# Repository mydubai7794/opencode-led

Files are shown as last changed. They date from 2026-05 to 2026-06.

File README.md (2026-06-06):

# AI LED Light

AI 编程助手实体指示灯 — 将 AI 编程助手的实时状态映射到桌面 LED 灯效，让你**一眼看到 AI 在干什么**。

支持 [OpenCode](https://opencode.ai) 插件和 [Claude Code](https://docs.anthropic.com/en/docs/claude-code) CLI，也兼容任何能发 MQTT 消息的 AI 编程工具。

## 功能特点

- **实时状态映射**：AI 思考时黄灯旋转、需要授权时红灯常亮、任务完成时绿灯、空闲时蓝灯呼吸、出错时红灯闪烁
- **一键安装**：`install.sh`（Linux/macOS）或 `install.bat`（Windows）安装依赖 + 部署插件，重启 OpenCode 即可使用
- **Claude Code 支持**：`install-claude.sh` / `install-claude.bat` 自动配置 Claude Code hooks，重启即可使用
- **跨平台 SSL**：Web 烧录服务器自动生成自签名证书，Windows/Linux/macOS 均可使用 HTTPS
- **双模式 MQTT**：支持本地内嵌 Broker（局域网）和远程 Mosquitto Broker（公网）
- **多项目协调**：多个 OpenCode / Claude Code 实例同时运行时，自动取最高优先级状态
- **Web 烧录器**：Chrome/Edge 浏览器直接烧录 ESP32 固件，零安装
- **WiFi 配网**：ESP32 开启热点，手机浏览器一键配网，无需写死配置
- **支持多款芯片**：ESP32-C3（WS2812 RGB 灯带）和 ESP8266（PWM LED）

## 架构

### 本地模式（默认）

```
┌─── 你的电脑（开发机）──────────────────────────────────────┐
│                                                            │
│  ┌─ OpenCode ─────────┐  ┌─ Claude Code ──────────────┐   │
│  │ ai-led.js 插件      │  │ hooks → claude-led-hook.mjs│   │
│  │  (进程内，捕获事件)   │  │  (每次事件 spawn)           │   │
│  │       │             │  │       │ HTTP POST            │   │
│  └───────┼─────────────┘  └───────┼────────────────────┘   │
│          │                        ↓                         │
│          │              claude-led-daemon.mjs               │
│          │              (常驻进程，持有 MQTT 连接)            │
│          ↓                        ↓                         │
│  MQTT publish ──────→ 内嵌 Broker (1883)                    │
│                                     │                      │
└─────────────────────────────────────┼──────────────────────┘
                                │ WiFi 局域网
                                ↓
                    ┌───────────────────────┐
                    │  ESP32 + WS2812 LED   │
                    │                       │
                    │  1. 连 WiFi           │
                    │  2. 连 MQTT Broker    │
                    │  3. 订阅 ai-led/state │
                    │  4. state → 灯效       │
                    └───────────────────────┘
```

### 远程模式

```
┌─── 你的电脑（开发机）──────────────────────────────────────┐
│                                                            │
│  ┌─ OpenCode ─────────┐  ┌─ Claude Code ──────────────┐   │
│  │ ai-led.js 插件      │  │ hooks → claude-led-hook.mjs│   │
│  │       │             │  │       │ HTTP POST            │   │
│  └───────┼─────────────┘  └───────┼────────────────────┘   │
│          │                        ↓                         │
│          │              claude-led-daemon.mjs               │
│          ↓                        ↓                         │
│  MQTT publish ──────→ 远程 Broker (公网)                    │
│                                     │                      │
└─────────────────────────────────────┼──────────────────────┘
                                │ 互联网
                                ↓
                    ┌───────────────────────┐
                    │  远程 Mosquitto Broker │
                    │  (Docker, 端口 1883)   │
                    │  需要用户名密码认证      │
                    └───────────┬───────────┘
                                │ 互联网/WiFi
                                ↓
                    ┌───────────────────────┐
                    │  ESP32 + WS2812 LED   │
                    │  连接远程 Broker       │
                    └───────────────────────┘
```

## LED 状态映射

| 状态 | LED 效果 | 触发条件 |
|---|---|---|
| `thinking` | 黄色跑马灯旋转 | AI 思考/输出/执行工具 |
| `auth_required` | 红灯常亮 | 需要用户授权 |
| `done` | 绿灯常亮 | 任务完成 |
| `idle` | 蓝灯呼吸(2s) | 空闲待机 |
| `error` | 红灯慢闪(1.6s) | 出错 |
| `config` | 紫灯呼吸(800ms) | 配网模式 |

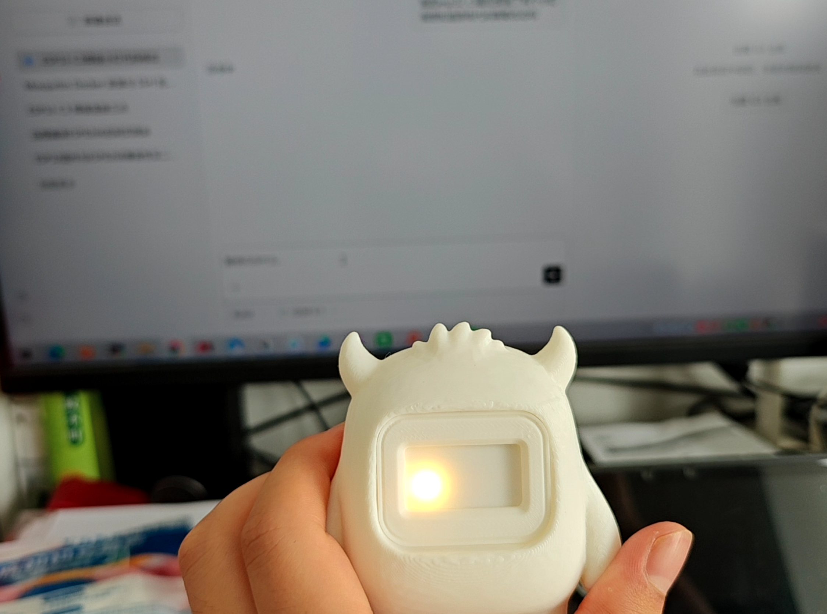
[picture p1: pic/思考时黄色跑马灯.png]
思考时黄色跑马灯

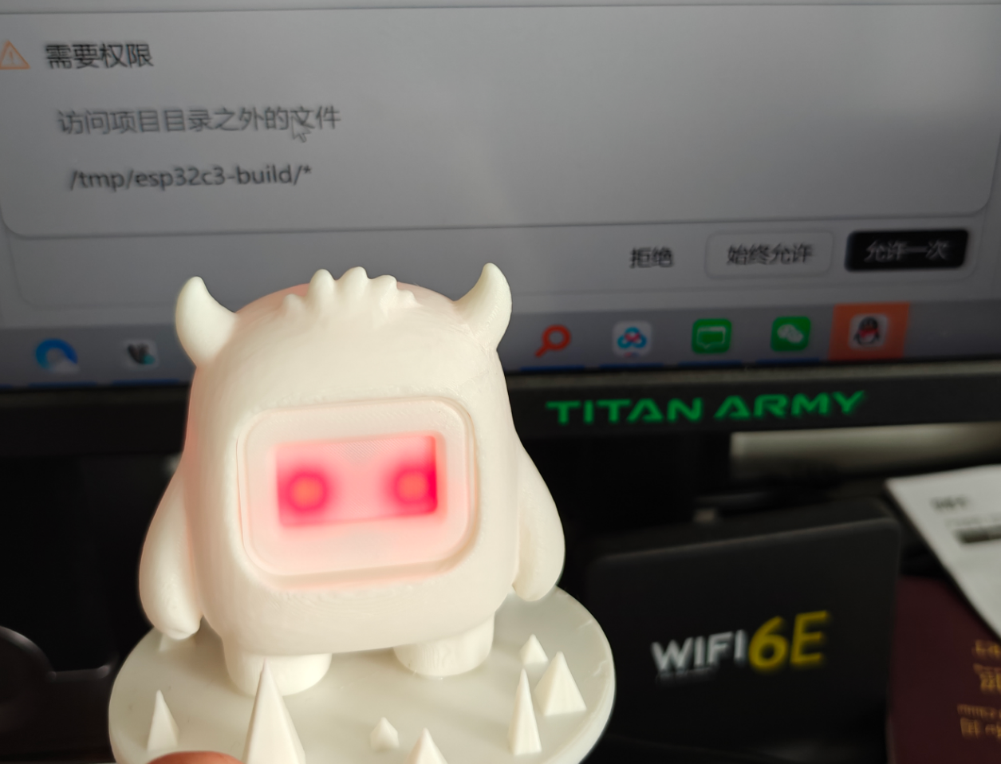
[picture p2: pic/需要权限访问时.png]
需要权限访问时

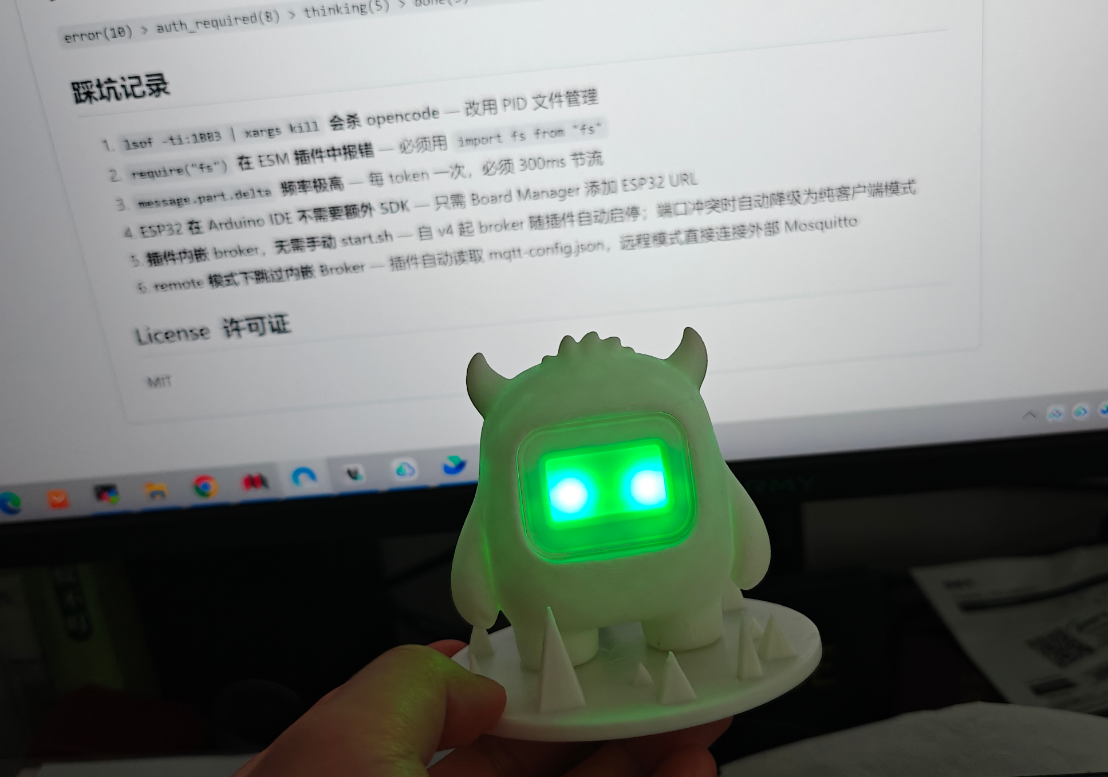
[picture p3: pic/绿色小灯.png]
绿色小灯

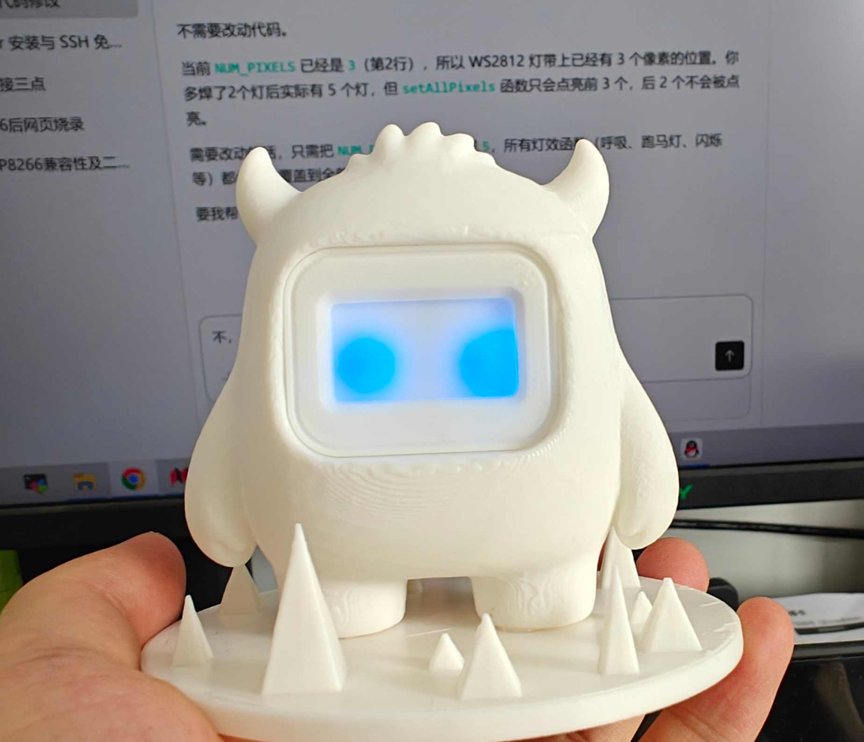
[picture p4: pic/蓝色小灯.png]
蓝色小灯


## 快速开始

### 0. 一句话提示词（给 AI 助手）

将以下提示词粘贴到你的 AI 编程助手（如 OpenCode）中，它会自动完成安装：

```
请克隆 https://github.com/mydubai7794/opencode-led 仓库，根据当前操作系统执行对应的安装脚本（Linux/macOS 用 bash install.sh，Windows 用 install.bat），安装完成后以本地模式启动插件。查看 README.md 了解详细用法。
```

### 1. 安装插件（OpenCode）

**Linux / macOS：**
```bash
git clone https://github.com/mydubai7794/opencode-led.git
cd opencode-led
bash install.sh
opencode
```

**Windows：**
```cmd
git clone https://github.com/mydubai7794/opencode-led.git
cd opencode-led
install.bat
opencode
```

无需手动启动 broker，插件加载时自动管理 MQTT Broker 生命周期。

### 1b. 安装插件（Claude Code）

**Linux / macOS：**
```bash
git clone https://github.com/mydubai7794/opencode-led.git
cd opencode-led
bash install-claude.sh
```

**Windows：**
```cmd
git clone https://github.com/mydubai7794/opencode-led.git
cd opencode-led
install-claude.bat
```

安装完成后重启 Claude Code 即可。LED daemon 会在首次使用时自动启动，无需手动操作。

**管理命令：**
```bash
npm run daemon:start   # 手动启动 daemon
npm run daemon:stop    # 停止 daemon
npm run daemon:status  # 查看运行状态
```

### 2. 配置 MQTT 模式

在项目根目录创建 `mqtt-config.json`（**已在 `.gitignore` 中，不会泄露凭据**），`install.sh` 安装时会自动复制到 `~/.config/opencode/plugins/` 目录。

> **local 模式**（局域网）只需要 `wifi` 和 `local` 即可，`remote` 部分可不填。

```json
{
  "mode": "local",
  "wifi": {
    "ssid": "你的WiFi名称",
    "password": "你的WiFi密码"
  },
  "local": {
    "host": "127.0.0.1",
    "port": 1883
  },
  "remote": {
    "host": "your-broker-ip",
    "port": 1883,
    "username": "",
    "password": ""
  }
}
```

| 字段 | 说明 |
|---|---|
| `mode` | `"local"` 或 `"remote"` |
| `wifi` | WiFi 凭据，编译固件时使用（插件忽略此字段） |
| `local.host/port` | 本地内嵌 Broker 地址（local 模式使用） |
| `remote.host/port` | 远程 Mosquitto Broker 地址（remote 模式使用） |
| `remote.username/password` | 远程 Broker 认证凭据（remote 模式必填） |

- **local 模式**：插件自动启动内嵌 aedes Broker，ESP32 与电脑在同一局域网
- **remote 模式**：连接远程 Mosquitto Broker，ESP32 可通过互联网访问，跳过内嵌 Broker

### 3. 开发调试

**Linux / macOS：**
```bash
npm install              # 安装依赖
bash start.sh            # 启动独立 Broker + Subscriber
node test-publisher.js   # 发送测试消息
bash stop.sh             # 停止（安全，不影响 opencode）
```

**Windows：**
```cmd
npm install
start.bat
node test-publisher.js
stop.bat
```

## 3D 打印外壳

项目提供了一个怪兽造型 LED 外壳的 3D 打印模型文件，适配 ESP32-C3 + WS2812 方案：

- **文件位置**：`model/monster-led-case.3mf`
- **格式**：.3mf（推荐使用 [Bambu Studio](https://bambulab.com/en/download/bambu-studio) 打开）
- **适配**：ESP32-C3 Super Mini + 2 颗 WS2812B 灯珠，USB-C 口对外露出
- **演示**：拓竹 A1 打印

## 硬件物料清单

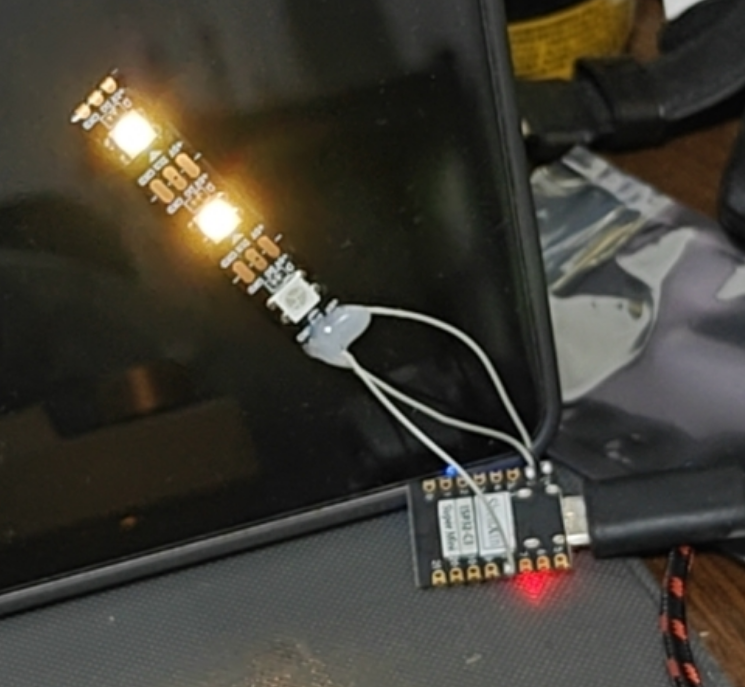
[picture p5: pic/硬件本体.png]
硬件本体


### 方案一：ESP32-C3 + WS2812 RGB 灯带（推荐）

| 部件 | 型号 | 参考价 | 备注 |
|---|---|---|---|
| MCU | ESP32-C3 Super Mini | ~¥8 | 合宙/乐鑫，USB-C 直插 |
| LED | WS2812B 灯带 (60颗/m) | ~¥5/米 | 只需截取 2 颗使用 |
| 按钮 | 轻触按键（可选） | ~¥0.1 | 重置配网（GPIO 9），也可不接 |
| USB-C 数据线 | | ~¥2 | 供电 + 烧录 |
| **合计** | | **~¥15** | |

接线：
```
ESP32-C3 Super Mini    WS2812B 灯带(2颗)
GPIO 8            →    DIN（数据输入）
5V                →    VCC（灯带供电）
GND               →    GND
GPIO 9            →    按钮 → GND（可选，重置配网）
```

> 灯带 2 颗串联共用一个数据线，固件中 `NUM_PIXELS=2`，所有 LED 同步显示相同颜色。

### 方案二：ESP8266 + PWM LED（三色灯）

| 部件 | 型号 | 参考价 | 备注 |
|---|---|---|---|
| MCU | ESP8266 (NodeMCU / Wemos D1) | ~¥8 | |
| LED | 3x 单色 LED（红/绿/蓝） | ~¥0.3 | GPIO 14/12/13 各接一颗 |
| 电阻 | 3x 220Ω | ~¥0.1 | LED 限流电阻 |
| 按钮 | 轻触按键（可选） | ~¥0.1 | 重置配网（GPIO 0） |
| USB 数据线 | | ~¥2 | 供电 + 烧录 |
| **合计** | | **~¥10** | |

接线：
```
ESP8266           LED
GPIO 14 (D5)  →  220Ω → 红色 LED (+)  → GND
GPIO 12 (D6)  →  220Ω → 绿色 LED (+)  → GND
GPIO 13 (D7)  →  220Ω → 蓝色 LED (+)  → GND
GPIO 0  (D3)  →  按钮 → GND（可选，重置配网）
```

## ESP32 固件烧录

### 方式一：Web Flasher（推荐，零安装）

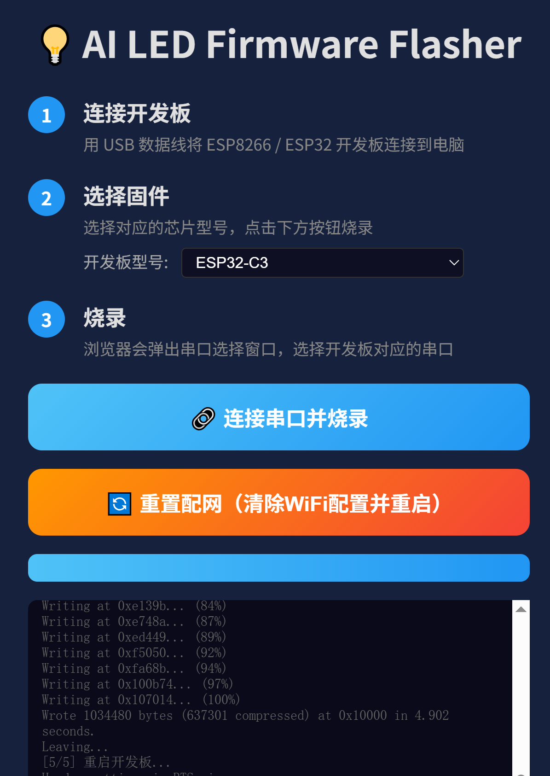
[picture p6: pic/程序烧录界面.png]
程序烧录界面


1. USB 线连接 ESP32 到电脑
2. 用 **Chrome/Edge** 打开 `flasher/index.html`（需本地 HTTP 服务）
3. 选择板子型号，点击"连接串口并烧录"

```bash
# 启动本地 HTTPS 服务（自动生成自签名证书，Windows/Linux/macOS 均可）
cd flasher
node server.mjs
# 浏览器打开 https://localhost:3000

# 或简单 HTTP 服务（仅本地，Web Serial API 限 localhost）
cd flasher
python3 -m http.server 8080
# 浏览器打开 http://localhost:8080
```

### 方式二：Arduino CLI（命令行编译）

```bash
# 1. 安装 Arduino CLI（一次性）
# Windows: 从 https://arduino.github.io/arduino-cli/latest/installation/ 下载
# Linux/macOS:
curl -fsSL https://raw.githubusercontent.com/arduino/arduino-cli/master/install.sh | sh

# 2. 配置（一次性）
arduino-cli config init
arduino-cli config add board_manager.additional_urls https://espressif.github.io/arduino-esp32/package_esp32_index.json
arduino-cli config add board_manager.additional_urls https://arduino.esp8266.com/stable/package_esp8266com_index.json
arduino-cli core update-index
arduino-cli core install esp32:esp32 esp8266:esp8266
arduino-cli lib install PubSubClient ArduinoJson "Adafruit NeoPixel"

# 3. 编译
arduino-cli compile --fqbn esp32:esp32:esp32c3 firmware/ai-led-firmware/ai-led-firmware.ino
arduino-cli compile --fqbn esp8266:esp8266:generic firmware/ai-led-firmware-esp8266/ai-led-firmware-esp8266.ino

# 4. 烧录（可选，也可用 Web Flasher）
arduino-cli upload -p COM3 --fqbn esp32:esp32:esp32c3 firmware/ai-led-firmware/
```

### 方式三：Arduino IDE
   - Arduino IDE → 文件 → 首选项 → 附加开发板管理器 URL，添加：
     ```
     https://espressif.github.io/arduino-esp32/package_esp32_index.json
     ```
   - 工具 → 开发板 → 开发板管理器 → 搜索 `esp32` → 安装

2. **安装库**：
   - 工具 → 管理库 → 搜索安装：
     - `PubSubClient`（MQTT 客户端）
     - `Adafruit NeoPixel`（WS2812 驱动，ESP32-C3 方案）
     - `ArduinoJson`（JSON 解析）

3. **烧录**：
   - 打开对应固件：
     - ESP32-C3：`firmware/ai-led-firmware/ai-led-firmware.ino`
     - ESP8266：`firmware/ai-led-firmware-esp8266/ai-led-firmware-esp8266.ino`
   - 选择开发板和端口，点击上传

4. **导出 .bin**（用于 Web Flasher 分发）：
   - 项目 → 导出已编译的二进制文件
   - 将 .bin 放到 `flasher/firmware/` 对应目录

## 固件本地配置（跳过配网）

调试固件时，每次烧录后都要重新配网很麻烦。项目支持将 WiFi 和 MQTT 凭据**编译进固件**，烧录即用，无需配网。

所有配置集中在 `mqtt-config.json` 一个文件中，只需添加 `wifi` 字段：

```json
{
  "mode": "local",
  "wifi": {
    "ssid": "你的WiFi名称",
    "password": "你的WiFi密码"
  },
  "local": {
    "host": "127.0.0.1",
    "port": 1883
  },
  "remote": {
    "host": "your-broker-ip",
    "port": 1883,
    "username": "",
    "password": ""
  }
}
```

- **插件**：只读 `mode` + `local`/`remote`，忽略 `wifi` 字段
- **固件编译**：`generate-firmware-config.js` 读取 `wifi` + 对应模式的 MQTT 配置，生成 `firmware-config.h` 编译进固件
- **`install.sh`** 会自动将 `mqtt-config.json` 复制到插件目录

### 编译流程

```bash
node generate-firmware-config.js
arduino-cli compile --fqbn esp32:esp32:esp32c3 firmware/ai-led-firmware/ai-led-firmware.ino
```

> 如果 `mqtt-config.json` 不存在或没有 `wifi` 字段，固件回退到 AP 配网模式。
> `mqtt-config.json` 已在 `.gitignore` 中，**不会被提交到仓库**。

## WiFi 配网

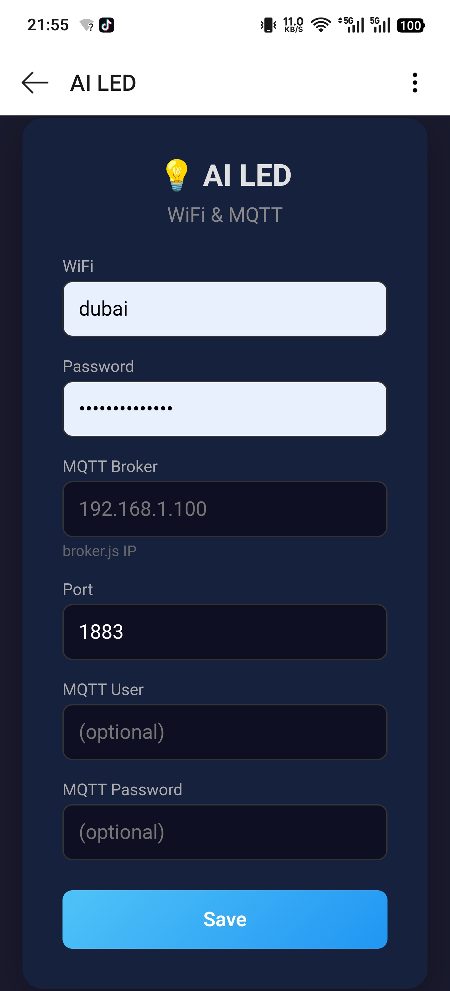
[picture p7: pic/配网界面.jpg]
配网界面


```
首次启动 / 长按按钮重置
       │
       ↓
ESP32 开启 AP 热点 "AI-LED-xxxx"（紫灯呼吸）
       │
       ↓
手机连接该 WiFi → 自动弹出配网页面
       │
       ↓
填写：WiFi名称 + WiFi密码 + 电脑IP + 端口(1883)
       │
       ↓
保存 → 自动重启 → 连接 WiFi → 连接 MQTT → 开始工作
```

重置配网：**长按按钮** → 清除配置 → 重启进入配网模式。也可通过 Web Flasher 的"重置配网"按钮发送串口命令。

## 项目结构

```
opencode-led/
├── package.json              # Node.js 依赖
├── mqtt-config.json          # MQTT 连接配置（local/remote 模式）
├── mqtt-shared.mjs           # 共享 MQTT/状态管理模块
├── opencode-plugin.js        # OpenCode 插件（支持本地/远程 MQTT）
├── claude-led-daemon.mjs     # Claude Code LED daemon（常驻 HTTP + MQTT 桥）
├── claude-led-hook.mjs       # Claude Code hook 脚本（轻量事件转发）
├── install.sh / install.bat  # OpenCode 一键安装
├── install-claude.sh / install-claude.bat  # Claude Code 一键安装
├── install-hooks-helper.cjs  # Claude Code hooks 配置工具
├── broker.js                 # 独立 MQTT Broker（调试用）
├── subscriber.js             # 测试订阅者（调试用）
├── test-publisher.js         # 独立测试发布者
├── start.sh / stop.sh        # 服务管理脚本（Linux/macOS，调试用）
├── start.bat / stop.bat      # 服务管理脚本（Windows，调试用）
├── firmware/
│   ├── ai-led-firmware/
│   │   └── ai-led-firmware.ino              # ESP32-C3 固件源码（WS2812）
│   └── ai-led-firmware-esp8266/
│       └── ai-led-firmware-esp8266.ino      # ESP8266 固件源码（PWM LED）
├── model/
│   └── monster-led-case.3mf  # 怪兽 LED 外壳 3D 打印模型
├── flasher/
│   ├── index.html            # Web Flasher 页面
│   ├── server.mjs            # HTTPS 烧录服务器（自动生成 SSL 证书）
│   ├── build.sh              # ESP8266 固件编译脚本
│   └── firmware/
│       ├── esp32c3/          # ESP32-C3 预编译固件
│       └── esp8266/          # ESP8266 预编译固件
└── README.md
```

## MQTT 协议

- **Broker（local 模式）**: `mqtt://<电脑IP>:1883`（内嵌 aedes，无需认证）
- **Broker（remote 模式）**: `mqtt://<远程服务器IP>:1883`（Mosquitto，需用户名密码认证）
- **Topic**: `ai-led/state`（协调结果）、`ai-led/project`（per-project 原始状态）
- **QoS**: 1

```json
{"state":"thinking","ts":1779251086068,"seq":1,"detail":"message.part.delta"}
```

## 事件映射

### OpenCode 事件

| OpenCode 事件 | LED 状态 | 说明 |
|---|-----|---|
| `permission.asked` | auth_required | 需要授权 |
| `permission.replied` | thinking | 授权后继续 |
| `question.asked` | auth_required | 弹出选择框 |
| `question.replied` | thinking | 选择后继续 |
| `message.part.delta` | thinking | AI 输出中（300ms 节流） |
| `session.diff` | thinking | 文件变更 |
| `session.status` | 心跳→done→idle | 状态轮询 |
| `session.idle` | done | 会话空闲 |
| `session.error` | done | 会话中断（用户停止/异常） |
| `tool.execute.before/after` | thinking | 执行工具 |

### Claude Code 事件

| Claude Code Hook | LED 状态 | 说明 |
|---|-----|---|
| `UserPromptSubmit` | thinking | 用户发送消息 |
| `PreToolUse` | thinking | 工具执行前 |
| `PostToolUse` | thinking | 工具执行后 |
| `PostToolBatch` | thinking | 批量工具完成 |
| `PermissionRequest` | auth_required | 需要用户授权 |
| `SubagentStart/Stop` | thinking | 子代理活动 |
| `Notification` | thinking | 通知事件 |
| `Stop` | done（延迟1s） | 响应结束 |
| `StopFailure` | error | API 错误 |
| `SessionEnd` | 清理会话 | 会话结束 |

Claude Code 通过 hooks 系统触发外部脚本，daemon 管理 HTTP 接口、状态机（含抑制、防抖、延迟 done）和 MQTT 发布。

## 优先级机制

多项目同时运行时，自动取最高优先级状态：

`error(10) > auth_required(8) > thinking(5) > done(3) > idle(0)`

## 踩坑记录

1. **`lsof -ti:1883 | xargs kill` 会杀 opencode** — 改用 PID 文件管理
2. **`require("fs")` 在 ESM 插件中报错** — 必须用 `import fs from "fs"`
3. **`message.part.delta` 频率极高** — 每 token 一次，必须 300ms 节流
4. **ESP32 在 Arduino IDE 不需要额外 SDK** — 只需 Board Manager 添加 ESP32 URL
5. **插件内嵌 broker，无需手动 start.sh** — 自 v4 起 broker 随插件自动启停；端口冲突时自动降级为纯客户端模式
6. **remote 模式下跳过内嵌 Broker** — 插件自动读取 mqtt-config.json，远程模式直接连接外部 Mosquitto
7. **ESP32-C3 Web Serial RTS 复位不可靠** — 烧录/擦除后必须拔掉 USB 线重新插入（物理断电重启），Web Serial 的硬复位信号无法让固件正常启动，不拔插会表现为找不到 WiFi 热点
8. **ESP32-C3 USB-Serial/JTAG 不支持应用层串口命令** — 打开串口时 DTR 信号翻转会复位芯片，PING/RESET 等文本命令在 ROM bootloader 阶段丢失；重置配网改用 esptool 擦除 flash + 重烧固件的方式
9. **Claude Code hooks 是无状态外部进程** — 每次 hook 触发 spawn 一个新进程，不能直接持有 MQTT 连接；用常驻 daemon + 轻量 hook 脚本架构，hook 通过 HTTP 转发事件到 daemon
10. **Windows Hyper-V 会保留端口范围** — daemon 首选端口可能被 EADDRINUSE/EACCES 拒绝，`findFreePort` 自动递增尝试最多 20 个端口，实际端口写入 `PORT_FILE` 供 hook 脚本发现
11. **GitHub Release 固件不能携带 hardcoded WiFi/MQTT 配置** — 发布的固件 bin 文件必须不带 `wifi` 字段编译（即 AP 配网模式），否则会泄露用户凭据；hardcoded 配置仅用于本地开发调试，通过 `mqtt-config.json`（已在 `.gitignore` 中）编译进固件

## 友情链接

- [Linux.do](https://linux.do)

## License

MIT

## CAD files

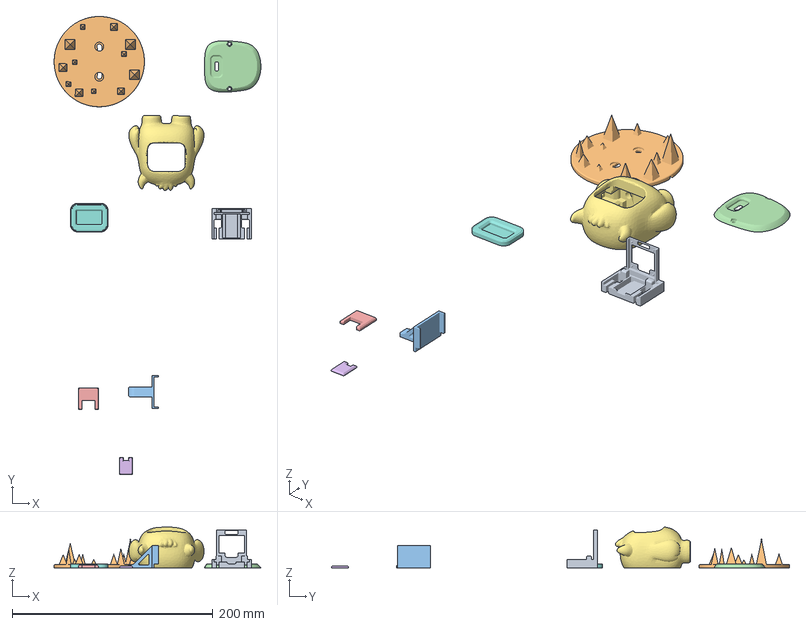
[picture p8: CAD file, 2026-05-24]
model/monster-led-case.3mf
206.0 x 456.3 x 40.6 mm
Yeti Full.stl_1
Yeti Full.stl_7
Yeti Full.stl_2
Yeti Full.stl_3
Yeti Full.stl_4
Yeti Full.stl_8
corp+face.stl_1
corp+face.stl_2_Boolean

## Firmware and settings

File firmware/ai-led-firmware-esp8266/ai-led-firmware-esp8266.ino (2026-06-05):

#define LED_TOP_PIN    14
#define LED_MID_PIN    12
#define LED_BOT_PIN    13
#define BUTTON_PIN     0
#define EEPROM_SIZE    512
#define CONFIG_VALID   0xA5
#define STATE_OFF_TIMEOUT 180000

#include <ESP8266WiFi.h>
#include <DNSServer.h>
#include <ESP8266WebServer.h>
#include <PubSubClient.h>
#include <EEPROM.h>
#include <ArduinoJson.h>

const uint8_t ledPins[] = {LED_TOP_PIN, LED_MID_PIN, LED_BOT_PIN};
const int NUM_LEDS = 3;

ESP8266WebServer server(80);
WiFiClient espClient;
PubSubClient mqtt(espClient);
DNSServer dnsServer;

struct Config {
  char valid;
  char ssid[33];
  char password[65];
  char broker[65];
  int brokerPort;
};

Config cfg;
char currentState[20] = "idle";
unsigned long stateStartTime = 0;
bool apMode = false;
bool buttonPressed = false;

const char portalHTML[] PROGMEM = R"rawliteral(
<!DOCTYPE html><html><head>
<meta charset='utf-8'><meta name='viewport' content='width=device-width,initial-scale=1'>
<title>AI LED</title>
<style>
*{box-sizing:border-box;margin:0;padding:0}
body{font-family:-apple-system,BlinkMacSystemFont,sans-serif;background:#1a1a2e;color:#e0e0e0;display:flex;justify-content:center;align-items:center;min-height:100vh}
.card{background:#16213e;border-radius:16px;padding:32px;width:90%;max-width:400px;box-shadow:0 8px 32px rgba(0,0,0,.3)}
h1{text-align:center;font-size:24px;margin-bottom:8px}
.sub{text-align:center;color:#888;margin-bottom:24px}
.field{margin-bottom:16px}
label{display:block;font-size:13px;color:#aaa;margin-bottom:4px}
input{width:100%;padding:12px;border:1px solid #333;border-radius:8px;background:#0f0f23;color:#fff;font-size:16px;outline:none}
input:focus{border-color:#4fc3f7}
button{width:100%;padding:14px;border:none;border-radius:8px;background:linear-gradient(135deg,#4fc3f7,#2196f3);color:#fff;font-size:16px;font-weight:600;cursor:pointer;margin-top:8px}
button:active{opacity:.8}
.status{text-align:center;margin-top:16px;padding:12px;border-radius:8px;display:none}
.ok{display:block;background:#1b5e20;color:#a5d6a7}
.fail{display:block;background:#b71c1c;color:#ef9a9a}
.hint{color:#666;font-size:12px;margin-top:4px}
</style>
</head><body>
<div class='card'>
<h1>&#x1F4A1; AI LED</h1>
<p class='sub'>WiFi &amp; MQTT</p>
<form onsubmit='return save(event)'>
<div class='field'><label>WiFi</label><input id='ssid' placeholder='SSID' required></div>
<div class='field'><label>Password</label><input id='pass' type='password' placeholder='password'></div>
<div class='field'><label>MQTT Broker</label><input id='broker' placeholder='192.168.1.100' required><p class='hint'>broker.js IP</p></div>
<div class='field'><label>Port</label><input id='port' value='1883' required></div>
<button type='submit'>Save</button>
</form>
<div id='status' class='status'></div>
</div>
<script>
async function save(e){
e.preventDefault();
const s=document.getElementById('status');
s.className='status';s.textContent='...';s.style.display='block';
const body=new URLSearchParams({ssid:document.getElementById('ssid').value,pass:document.getElementById('pass').value,broker:document.getElementById('broker').value,port:document.getElementById('port').value});
try{
const r=await fetch('/save',{method:'POST',body:body});
const j=await r.json();
if(j.ok){s.className='status ok';s.textContent='OK! Rebooting...';}
else{s.className='status fail';s.textContent='Error: '+j.error;}
}catch(ex){s.className='status fail';s.textContent='Failed';}
}
</script>
</body></html>
)rawliteral";

void loadConfig() {
  EEPROM.begin(EEPROM_SIZE);
  EEPROM.get(0, cfg);
  EEPROM.end();
  if (cfg.valid != CONFIG_VALID) {
    memset(&cfg, 0, sizeof(cfg));
  }
}

void saveConfig() {
  EEPROM.begin(EEPROM_SIZE);
  EEPROM.put(0, cfg);
  EEPROM.commit();
  EEPROM.end();
}

void clearConfig() {
  memset(&cfg, 0, sizeof(cfg));
  EEPROM.begin(EEPROM_SIZE);
  EEPROM.put(0, cfg);
  EEPROM.commit();
  EEPROM.end();
}

void setLED(int index, int brightness) {
  if (index < 0 || index >= NUM_LEDS) return;
  int val = constrain(brightness, 0, PWM_RANGE);
  analogWrite(ledPins[index], val);
}

void setAllLEDs(int brightness) {
  for (int i = 0; i < NUM_LEDS; i++) {
    setLED(i, brightness);
  }
}

void solidLED(int brightness) {
  setAllLEDs(brightness);
}

void breathLED(unsigned long period) {
  float t = (float)(millis() % period) / period;
  float b = (sin(t * 2 * PI) + 1) / 2;
  int val = (int)(b * PWM_RANGE);
  setAllLEDs(val);
}

void blinkLED(unsigned long period) {
  bool on = (millis() % period) < (period / 2);
  if (on) setAllLEDs(PWM_RANGE);
  else setAllLEDs(0);
}

void marqueeLED(unsigned long period) {
  unsigned long phase = millis() % period;
  float angle = ((float)phase / period) * 2 * PI;
  for (int i = 0; i < NUM_LEDS; i++) {
    float a = angle + (float)i * (2 * PI / NUM_LEDS);
    float b = (sin(a) + 1) / 2;
    float br = b * b;
    setLED(i, (int)(br * PWM_RANGE));
  }
}

unsigned long doneStartTime = 0;
bool doneActive = false;

void doneLED() {
  if (!doneActive) {
    doneActive = true;
    doneStartTime = millis();
  }
  unsigned long elapsed = millis() - doneStartTime;
  if (elapsed < 1500) {
    int cycle = elapsed / 250;
    if (cycle % 2 == 0) setAllLEDs(PWM_RANGE);
    else setAllLEDs(0);
  } else {
    setAllLEDs(0);
  }
}

void updateLED() {
  if (strcmp(currentState, "thinking") == 0) {
    doneActive = false;
    marqueeLED(800);
  } else if (strcmp(currentState, "auth_required") == 0) {
    doneActive = false;
    solidLED(PWM_RANGE);
  } else if (strcmp(currentState, "done") == 0) {
    doneLED();
  } else if (strcmp(currentState, "idle") == 0) {
    doneActive = false;
    breathLED(2000);
  } else if (strcmp(currentState, "error") == 0) {
    doneActive = false;
    blinkLED(1600);
  } else if (strcmp(currentState, "config") == 0) {
    doneActive = false;
    breathLED(800);
  } else if (strcmp(currentState, "off") == 0) {
    doneActive = false;
    setAllLEDs(0);
  } else {
    doneActive = false;
    setAllLEDs(0);
  }
}

void setState(const char* state) {
  if (strcmp(currentState, state) != 0) {
    strncpy(currentState, state, sizeof(currentState) - 1);
    currentState[sizeof(currentState) - 1] = 0;
    doneActive = false;
    stateStartTime = millis();
  }
}

void mqttCallback(char* topic, byte* payload, unsigned int length) {
  char buf[128];
  int len = length < 127 ? length : 127;
  memcpy(buf, payload, len);
  buf[len] = 0;

  StaticJsonDocument<128> doc;
  DeserializationError err = deserializeJson(doc, buf);
  if (err) return;

  const char* state = doc["state"];
  if (state) setState(state);
}

void reconnectMQTT() {
  int attempts = 0;
  while (!mqtt.connected() && attempts < 3) {
    String clientId = "ai-led-" + String(ESP.getChipId(), HEX);
    if (mqtt.connect(clientId.c_str())) {
      mqtt.subscribe("ai-led/state", 1);
    } else {
      delay(2000);
    }
    attempts++;
  }
  if (!mqtt.connected()) {
    setState("error");
  }
}

bool connectWiFi() {
  WiFi.mode(WIFI_STA);
  WiFi.begin(cfg.ssid, cfg.password);
  unsigned long start = millis();
  while (WiFi.status() != WL_CONNECTED && millis() - start < 15000) {
    delay(500);
    updateLED();
  }
  return WiFi.status() == WL_CONNECTED;
}

void startAP() {
  apMode = true;
  WiFi.mode(WIFI_AP);
  String apName = "AI-LED-" + String(ESP.getChipId(), HEX);
  WiFi.softAP(apName.c_str());
  setState("config");

  server.on("/", HTTP_GET, []() {
    server.send_P(200, "text/html", portalHTML);
  });

  server.on("/save", HTTP_POST, []() {
    String ssid = server.arg("ssid");
    String pass = server.arg("pass");
    String broker = server.arg("broker");
    int port = server.arg("port").toInt();

    strncpy(cfg.ssid, ssid.c_str(), sizeof(cfg.ssid) - 1);
    cfg.ssid[sizeof(cfg.ssid) - 1] = 0;
    strncpy(cfg.password, pass.c_str(), sizeof(cfg.password) - 1);
    cfg.password[sizeof(cfg.password) - 1] = 0;
    strncpy(cfg.broker, broker.c_str(), sizeof(cfg.broker) - 1);
    cfg.broker[sizeof(cfg.broker) - 1] = 0;
    cfg.brokerPort = port ? port : 1883;
    cfg.valid = CONFIG_VALID;
    saveConfig();

    server.send(200, "application/json", "{\"ok\":true}");
    delay(500);
    ESP.restart();
  });

  server.onNotFound([]() {
    server.sendHeader("Location", "http://" + WiFi.softAPIP().toString());
    server.send(302);
  });

  dnsServer.start(53, "*", WiFi.softAPIP());
  server.begin();
}

void setup() {
  for (int i = 0; i < NUM_LEDS; i++) {
    pinMode(ledPins[i], OUTPUT);
    analogWrite(ledPins[i], 0);
  }
  analogWriteRange(PWM_RANGE);
  analogWriteFreq(PWM_FREQ);
  pinMode(BUTTON_PIN, INPUT_PULLUP);

  loadConfig();

  if (cfg.valid != CONFIG_VALID) {
    startAP();
    return;
  }

  if (!connectWiFi()) {
    startAP();
    return;
  }

  mqtt.setServer(cfg.broker, cfg.brokerPort);
  mqtt.setCallback(mqttCallback);
  mqtt.setKeepAlive(10);
  reconnectMQTT();
}

void loop() {
  if (digitalRead(BUTTON_PIN) == LOW && !buttonPressed) {
    buttonPressed = true;
    delay(50);
    if (digitalRead(BUTTON_PIN) == LOW) {
      clearConfig();
      delay(100);
      ESP.restart();
    }
  }
  if (digitalRead(BUTTON_PIN) == HIGH) {
    buttonPressed = false;
  }

  if (apMode) {
    server.handleClient();
    dnsServer.processNextRequest();
    updateLED();
    return;
  }

  if (!mqtt.connected()) {
    reconnectMQTT();
  }
  mqtt.loop();
  if (strcmp(currentState, "done") == 0 || strcmp(currentState, "idle") == 0) {
    if (millis() - stateStartTime > STATE_OFF_TIMEOUT) {
      strncpy(currentState, "off", sizeof(currentState) - 1);
      currentState[sizeof(currentState) - 1] = 0;
      Serial.println("[AI-LED] done/idle 3min, LED off");
    }
  }
  updateLED();
}

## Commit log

2026-05-23 Initial commit: AI LED Light - AI编程助手实体指示灯
    - OpenCode 插件捕获事件，MQTT 传输到 ESP32 + WS2812 LED
    - 支持 local/remote 双模式 MQTT
    - 多项目优先级协调机制
    - ESP32-C3 + ESP8266 双固件支持
    - Web Flasher 零安装烧录
    - WiFi 配网
2026-05-23 feat: 3分钟无MQTT消息自动关灯
2026-05-23 fix: 修复Web Flasher重置配网功能不可用
    根因：ESP32-C3 USB CDC串口在port.open()时触发DTR信号导致芯片复位，
    RESET命令在重启期间丢失。同时connectWiFi()阶段未调用handleSerial()，
    导致芯片连WiFi期间也无法接收RESET命令。
    修复：
    - 固件：connectWiFi()和reconnectMQTT()等待循环中增加handleSerial()调用
    - 固件：增加PING/PONG串口握手协议
    - 固件：clearConfig()增加EEPROM写入诊断日志和回读验证
    - 固件：RESET后延时从100ms增加到500ms确保flash写入完成
    - Web Flasher：sendReset()等待5秒DTR复位完成后再发送RESET，最多重试3次
    - Web Flasher：实时显示设备串口输出日志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
    [ai-led-firmware.ino]
2026-05-23 fix: 修复插件状态机，增加isSessionActive防止误触发done状态
    多个事件（tool.execute.before/permission.asked/question.asked等）触发时
    需标记session活跃，避免session.idle和session.status超时误将状态切为done。
    isSessionActive确保只有真正活跃过才会触发done。
2026-05-23 fix: Web Flasher烧录/重置后提示拔USB重启，更新踩坑记录
    - 烧录时eraseAll改为true，确保清除旧配置进入配网模式
    - 重置配网改用esptool-js擦除flash+重烧固件（ESP32-C3 USB-Serial/JTAG不支持串口文本命令）
    - 烧录和重置成功提示改为醒目提醒拔掉USB线物理断电重启
    - mqtt-config.json加入.gitignore并从追踪中移除
    - README新增第7、8条踩坑记录
2026-05-23 feat: 添加Windows安装脚本，跨平台SSL证书自动生成
    - 新增 install.bat/start.bat/stop.bat Windows版本脚本
    - server.mjs SSL证书改用selfsigned库，不再依赖openssl命令
    - broker.js/subscriber.js PID文件路径改用os.tmpdir()，跨平台兼容
    - README添加Windows安装说明、AI提示词用法、跨平台文档
2026-05-23 docs: 添加演示图片及README对应描述
2026-05-23 fix: 修复思考完成后黄灯持续闪烁，添加PlatformIO编译支持
    - opencode-plugin: 添加suppressThinkingUntil窗口，防止session.idle后迟到事件重新触发thinking
    - opencode-plugin: LOG_FILE路径改用os.tmpdir()兼容Windows
    - firmware(esp32): 3分钟超时关灯仅限idle状态，thinking不再被误关
    - 添加platformio.ini和src/目录支持PlatformIO CLI编译
2026-05-23 docs: 添加PlatformIO编译说明到README
2026-05-23 docs: 明确烧录方式为Web Flasher或Arduino IDE，PlatformIO仅用于编译
2026-05-23 fix: 结合pendingDone+suppressThinking双重防护，修复Windows迟到事件重新触发thinking
2026-05-23 fix: ESP8266固件也仅idle状态3分钟超时关灯
2026-05-23 refactor: 删除PlatformIO相关文件，改用Arduino CLI编译，只保留.ino源码
2026-05-23 fix: 提取activateSession统一抑制检查，防止done后trailing事件回跳thinking
2026-05-23 fix: 移除日志中的broker地址和SSID明文打印
2026-05-24 feat: 新增 Claude Code CLI 支持，通过 hooks + daemon 架构控制 LED 状态灯
    - 新增 claude-led-daemon.mjs：常驻 HTTP daemon，管理 session 状态机并发布 MQTT
    - 新增 claude-led-hook.mjs：轻量 hook 脚本，转发 Claude Code 事件到 daemon
    - 新增 mqtt-shared.mjs：从 opencode-plugin.js 提取共享 MQTT/状态管理模块
    - 新增 install-claude.bat/sh：一键安装脚本，自动配置 Claude Code hooks
    - 支持端口冲突自动切换（findFreePort 递增尝试最多20个端口）
    - 完整移植 opencode-plugin.js 的状态抑制、pending done 延迟、debounce 逻辑
    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
2026-05-24 fix: 防止Stop后trailing事件(Notification)回跳thinking
    Stop/StopFailure标记sessionActive=false，markThinking检查
    该标记，只有UserPromptSubmit能重新激活session
2026-05-24 feat: 添加怪兽 LED 外壳 3D 打印模型文件
    [monster-led-case.3mf]
2026-05-24 fix: 修正灯珠数量为 2 颗（README + 固件）
    [ai-led-firmware.ino]
2026-05-25 fix: 修复MQTT listener内存泄漏、缩短thinking抑制期、error灯效改紫色呼吸
2026-05-25 fix: 通过subagent深度追踪修复子agent完成后误报done导致绿灯闪烁
2026-05-27 fix: 固件超时熄灯仅限done/idle状态，修复thinking/auth_required期间误熄灯
2026-05-28 fix: 协调器心跳保活+固件仅idle熄灯，修复thinking期间灯灭
2026-05-29 feat: WiFi硬编码配置+协调器done循环修复+ESP32 alive心跳+固件编译流程规范化
2026-06-05 fix: 移除超时熄灯/心跳保活逻辑，session.error映射为done，固件仅idle/done超时关灯
2026-06-05 docs: 添加固件本地配置说明，更新session.error事件映射
2026-06-05 refactor: 统一配置源，废弃firmware-config.json，WiFi+MQTT配置合并到mqtt-config.json
2026-06-05 docs: 补充mqtt-config.json创建位置和安装自动复制说明
2026-06-05 feat: 添加mqtt-config.json.example示例文件，install.sh/bat自动复制配置
2026-06-06 fix: install.bat 容错处理，自动创建配置目录和最小配置文件
2026-06-06 docs: 添加踩坑记录 - Release 固件不能携带 hardcoded WiFi 配置
